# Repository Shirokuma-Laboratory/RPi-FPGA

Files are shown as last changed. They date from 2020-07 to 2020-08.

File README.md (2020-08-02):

# RPi-FPGA LMCXO2-100 (Now Testing)
ラティス・セミコンダクタ MachXO2 FPGA を用いた Raspberry Pi I/O 拡張モジュール  
Raspberry Pi I/O extention module using Lattice semiconductor MachXO2 FPGA.

このモジュールは、ラティス・セミコンダクタ MachXO2 FPGA の 0.5mm ピッチ TQFP 100ピン・パッケージ・デバイス 向けに設計されました。  
This module is desined for 0.5mm pitch TQFP 100pin package devices of Lattice semiconductor MachXO2 FPGAs.  
Raspberry Pi から 3.3v の供給を受け、コア電圧 3.3v のHC型デバイスが使えます。  
Since 3.3v power is supplied from Raspberry Pi, the HC type devices that has 3.3v of the core voltages can be used.  
Table 1 に、Lattice semiconductor MachXO2 FPGA シリーズの利用可能なモデルとその機能を示します。  
Table 1 shows available models and features of Lattice semiconductor MachXO2 FPGAs.  
  
Table 1: Available Models and features of Lattice semiconductor MachXO2 FPGAs.
|model|XO2-256|XO2-640|XO2-1200|XO2-2000|
|:---:|---:|---:|---:|---:|
|LUTs |256|640|1280|2112|
|I/Os |55|78|79|79| 
|EBR SRAM<br>(kbits)|0|18|64|74|
|Dist SRAM<br>(kbits)|2|5|10|16|
|Flash<br>(kbits)|0|24|64|80|
|PLL|0|0|1|1|

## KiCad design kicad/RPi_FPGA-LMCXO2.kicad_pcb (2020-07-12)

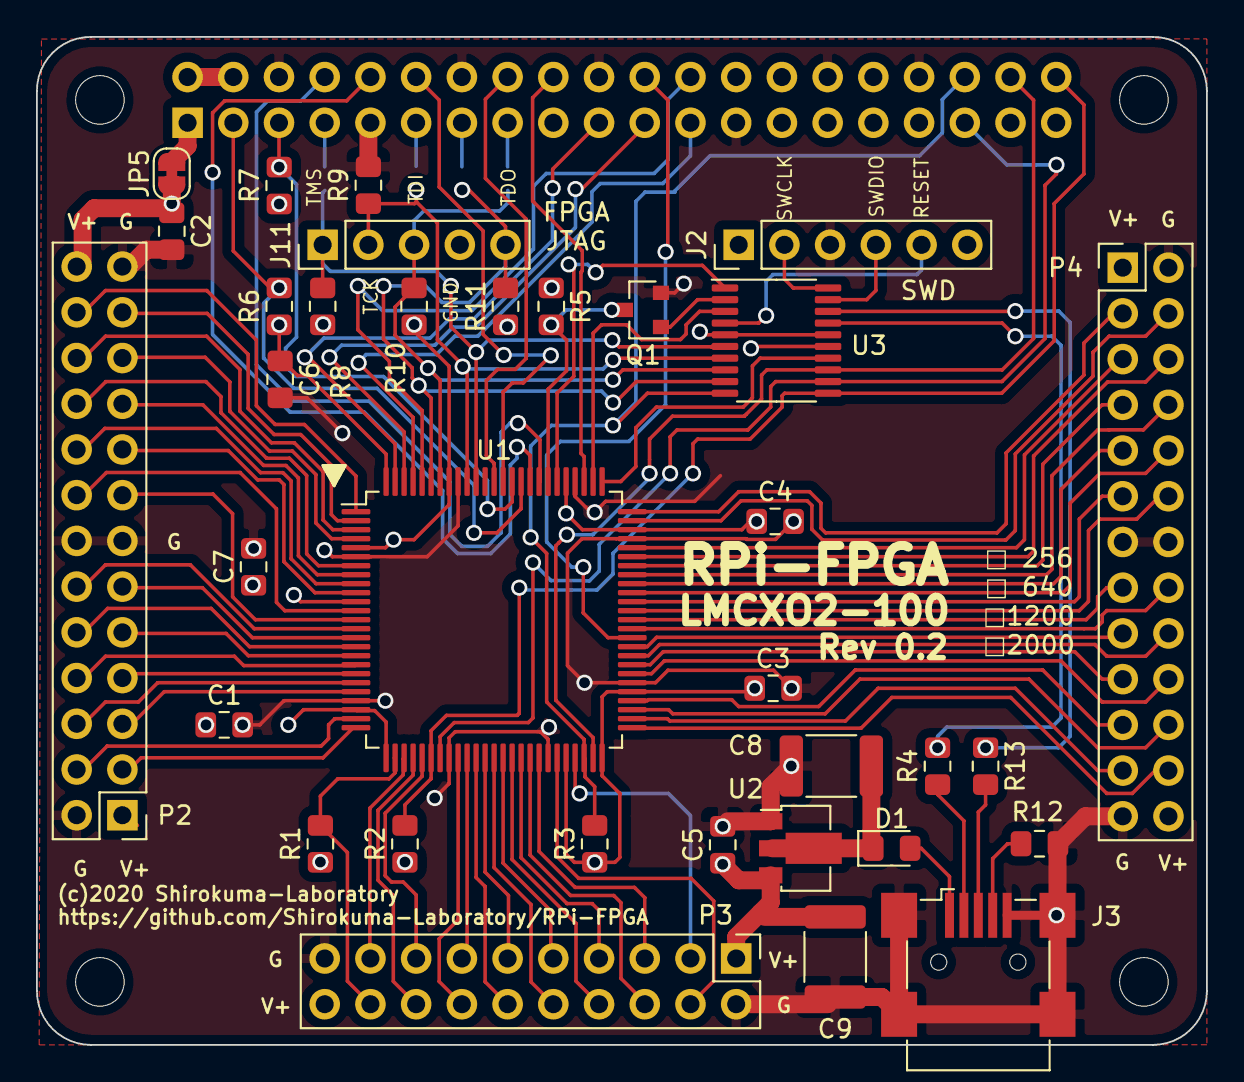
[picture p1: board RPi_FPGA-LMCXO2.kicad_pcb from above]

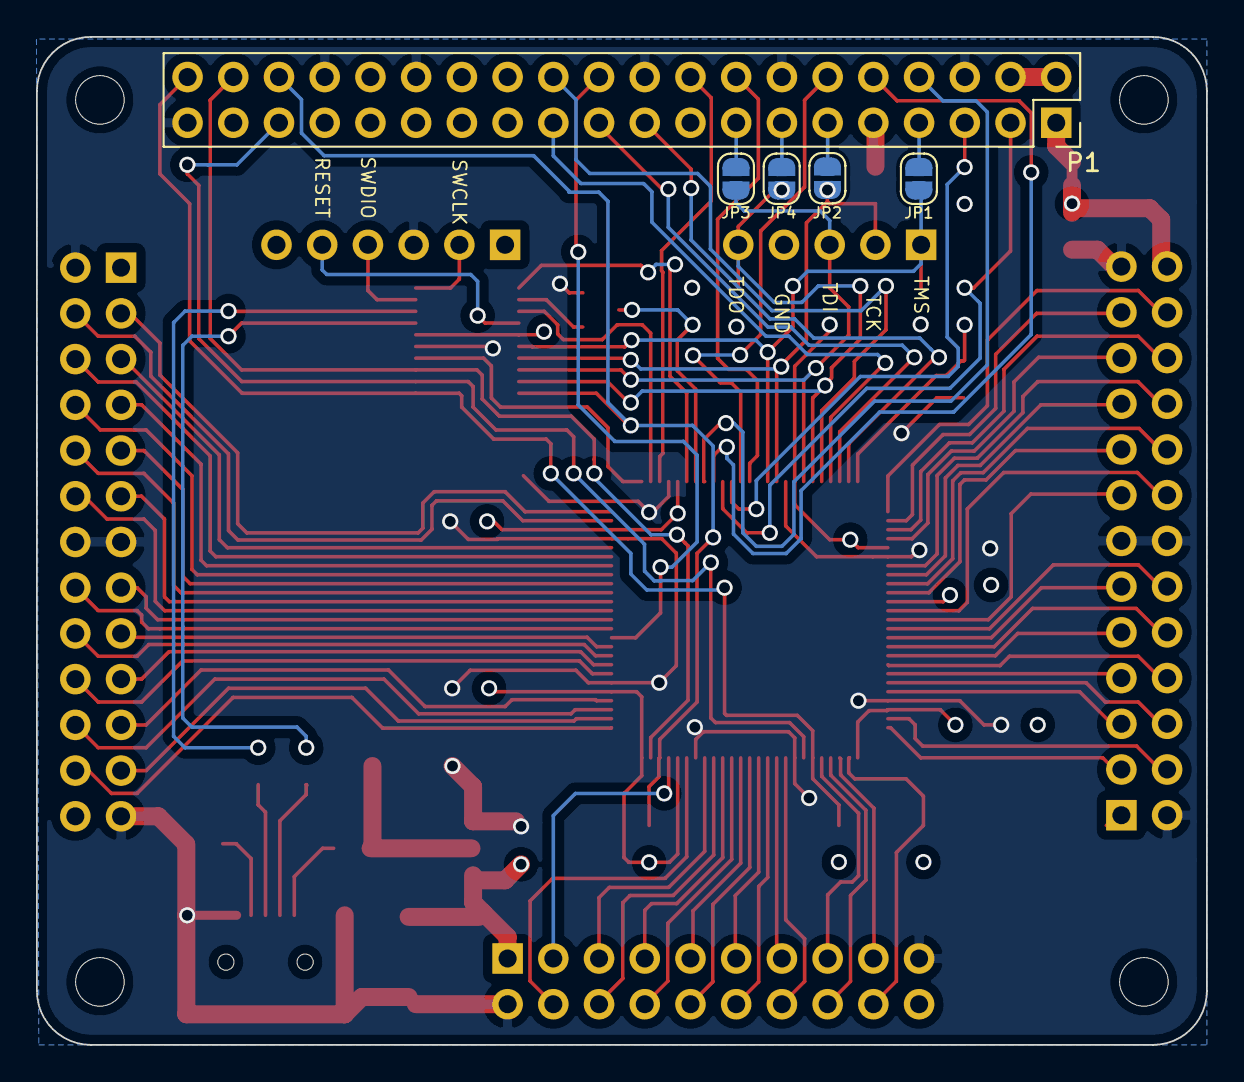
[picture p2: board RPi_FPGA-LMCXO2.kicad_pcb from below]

Board: 4 copper layers, 65.0 x 56.0 mm, 43 parts (5 on the bottom side), 99 nets.

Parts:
C1, C2, C3, C4, C5, C6, C7: 0.1u; C_0805_2012Metric_Pad1.15x1.40mm_HandSolder
C8, C9: 10u; C_1812_4532Metric_Pad1.30x3.40mm_HandSolder
D1: D; D_0805_2012Metric_Pad1.15x1.40mm_HandSolder
J2: SWD; PinHeader_1x06_P2.54mm_Vertical
J3: USB_B_Mini; USB_Mini-B_Wuerth_65100516121_Horizontal
J11: JTAG; PinHeader_1x05_P2.54mm_Vertical
JP1, JP2, JP3, JP4: SolderJumper_2_Open; SolderJumper-2_P1.3mm_Open_RoundedPad1.0x1.5mm
JP5: SolderJumper_2_Bridged; SolderJumper-2_P1.3mm_Bridged_RoundedPad1.0x1.5mm
MK1, MK2, MK3, MK4: M2.5; MountingHole_2.7mm_M2.5
P1: RPi-I/O; PinSocket_2x20_P2.54mm_Vertical
P2: Ext-I/O-1; PinHeader_2x13_P2.54mm_Vertical
P3: Ext_I/O-2; PinHeader_2x10_P2.54mm_Vertical
P4: Conn_02x13_Odd_Even; PinHeader_2x13_P2.54mm_Vertical
Q1: DTC144G; SOT-23
R1, R2, R3: 4K7; R_0805_2012Metric_Pad1.15x1.40mm_HandSolder
R4, R13: R; R_0805_2012Metric_Pad1.15x1.40mm_HandSolder
R5, R6, R7, R8, R9, R10, R11: 4k7; R_0805_2012Metric_Pad1.15x1.40mm_HandSolder
R12: 100k; R_0805_2012Metric_Pad1.15x1.40mm_HandSolder
U1: LMCXO2-2000-100; LQFP-100_14x14mm_P0.5mm
U2: MCP1700-3302E_SOT89; SOT-89-3
U3: STM32F042F4Px; TSSOP-20_4.4x6.5mm_P0.65mm

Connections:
+3V3: C1.1, C2.1, C3.1, C4.1, C5.1, C6.1, C7.1, C9.1, J2.1, JP5.1, P2.1, P2.26, P3.1, P3.20, P4.1, P4.26, R1.1, R2.1, R3.1, R5.1, R6.1, R7.1, R8.1, R10.1, R11.1, U1.5, U1.11, U1.23, U1.26, U1.46, U1.50, U1.55, U1.73, U1.80, U1.93, U1.100, U2.3, U3.5, U3.16
+5V: P1.2, P1.4
/GPIO2(SDA1): P1.3, R6.2, U1.85
/GPIO3(SCL1): P1.5, R7.2, U1.86
/GPIO4(GCLK): JP1.2, P1.7
/GPIO8(SPI0_CE_N): P1.24, U1.96
/GPIO9(SPI0_MISO): P1.21, U1.98
/GPIO10(SPI0_MOSI): P1.19, U1.99
/GPIO11(SPI0_SCK): P1.23, U1.97
/GPIO14(TXD0): P1.8, U1.83
/GPIO15(RXD0): P1.10, U1.84
/GPIO16: P1.36, R3.2, U1.48, U3.10
/GPIO17(GEN0): JP2.2, P1.11
/GPIO18(GEN1)(PWM0): P1.12, U1.87
/GPIO19(SPI1_MISO): P1.35, U1.32, U3.12
/GPIO20(SPI1_MOSI): P1.38, U1.49, U3.13
/GPIO21(SPI1_SCK): P1.40, R2.2, U1.31, U3.11
/GPIO22(GEN3): JP3.2, P1.15
/GPIO23(GEN4): P1.16, U1.88
/GPIO24(GEN5): P1.18, U1.78
/GPIO25(GEN6): P1.22, U1.61
/GPIO27(GEN2): JP4.2, P1.13
/LMCXO2-A/PB5A: P3.18, R1.2, U1.27
/LMCXO2-A/PB5B: P3.17, U1.28
/LMCXO2-A/PB6A: P3.16, U1.29
/LMCXO2-A/PB6B: P3.15, U1.30
/LMCXO2-A/PB11A: P3.14, U1.34
/LMCXO2-A/PB11B: P3.13, U1.35
/LMCXO2-A/PB12A: P3.12, U1.36
/LMCXO2-A/PB12B: P3.11, U1.37
/LMCXO2-A/PB16A: P3.10, U1.38
/LMCXO2-A/PB16B: P3.9, U1.39
/LMCXO2-A/PB18A: P3.8, U1.40
/LMCXO2-A/PB18B: P3.7, U1.41
/LMCXO2-A/PB21A: P3.6, U1.42
/LMCXO2-A/PB21B: P3.5, U1.43
/LMCXO2-A/PB22A: P3.4, U1.45
/LMCXO2-A/PB22B: P3.3, U1.47
/LMCXO2-A/PL2A: P2.24, U1.1
/LMCXO2-A/PL2B: P2.23, U1.2
/LMCXO2-A/PL3A: P2.22, U1.3
/LMCXO2-A/PL3B: P2.21, U1.4
/LMCXO2-A/PL4A: P2.20, U1.7
/LMCXO2-A/PL4B: P2.19, U1.8
/LMCXO2-A/PL5A: P2.18, U1.9
/LMCXO2-A/PL5B: P2.17, U1.10
/LMCXO2-A/PL7C: P2.16, U1.12
/LMCXO2-A/PL7D: P2.15, U1.13
/LMCXO2-A/PL9A: P2.12, U1.14
/LMCXO2-A/PL9B: P2.11, U1.15
/LMCXO2-A/PL10A: P2.10, U1.16
/LMCXO2-A/PL10B: P2.9, U1.17
/LMCXO2-A/PL11A: P2.8, U1.18
/LMCXO2-A/PL11B: P2.7, U1.19
/LMCXO2-A/PL12A: P2.6, U1.20
/LMCXO2-A/PL12B: P2.5, U1.21
/LMCXO2-A/PL14A: P2.4, U1.24
/LMCXO2-A/PL14B: P2.3, U1.25
/LMCXO2-B/DONE: U1.76, U3.14
/LMCXO2-B/INITN: U1.77, U3.3
/LMCXO2-B/JTAGENB: Q1.3, R5.2, U1.82
/LMCXO2-B/PR2A: P4.3, U1.75
/LMCXO2-B/PR2B: P4.4, U1.74
/LMCXO2-B/PR3A: P4.5, U1.71
/LMCXO2-B/PR3B: P4.6, U1.70
/LMCXO2-B/PR4A: P4.7, U1.69
/LMCXO2-B/PR4B: P4.8, U1.68
/LMCXO2-B/PR5A: P4.9, U1.67
/LMCXO2-B/PR5B: P4.10, U1.66
/LMCXO2-B/PR6A: P4.11, U1.65
/LMCXO2-B/PR6B: P4.12, U1.64
/LMCXO2-B/PR7A: P4.15, U1.63
/LMCXO2-B/PR7B: P4.16, U1.62
/LMCXO2-B/PR10A: P4.17, U1.60
/LMCXO2-B/PR10B: P4.18, U1.59
/LMCXO2-B/PR11A: P4.19, U1.58
/LMCXO2-B/PR11B: P4.20, U1.57
/LMCXO2-B/PR12A: P4.21, U1.54
/LMCXO2-B/PR12B: P4.22, U1.53
/LMCXO2-B/PR14A: P4.23, U1.52
/LMCXO2-B/PR14B: P4.24, U1.51
/LMCXO2-B/PRGM: U1.81, U3.1
/STM32F042F/JTAGEN: Q1.1, U3.2
/STM32F042F/RESET: J2.5, U3.4
/STM32F042F/SWCLK: J2.2, U3.20
/STM32F042F/SWDIO: J2.4, U3.19
/STM32F042F/USB_DM: R4.1, U3.17
/STM32F042F/USB_DP: R13.1, U3.18
/TCK: J11.2, JP2.1, R9.1, U1.91, U3.7
/TDI: J11.3, JP3.1, R10.2, U1.94, U3.8
/TDO: J11.5, JP4.1, R11.2, U1.95, U3.9
/TMS: J11.1, JP1.1, R8.2, U1.90, U3.6
GND: C1.2, C2.2, C3.2, C4.2, C5.2, C6.2, C7.2, C8.2, C9.2, J2.3, J3.5, J3.6, J11.4, P1.6, P1.9, P1.14, P1.20, P1.25, P1.30, P1.34, P1.39, P2.2, P2.13, P2.14, P2.25, P3.2, P3.19, P4.2, P4.13, P4.14, P4.25, Q1.2, R9.2, R12.1, U1.6, U1.22, U1.33, U1.44, U1.56, U1.72, U1.79, U1.92, U2.1, U3.15
unnamed: C8.1, D1.1, U2.2
unnamed: D1.2, J3.1
unnamed: J3.2, R4.2
unnamed: J3.3, R13.2
unnamed: J3.4, R12.2
unnamed: JP5.2, P1.1, P1.17

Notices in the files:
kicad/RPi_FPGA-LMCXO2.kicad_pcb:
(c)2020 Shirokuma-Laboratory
